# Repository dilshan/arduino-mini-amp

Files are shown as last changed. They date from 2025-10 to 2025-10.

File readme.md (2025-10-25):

# Arduino Mini Amplifier

The **Arduino Mini Amplifier** is a complete, open-source audio amplifier system that combines vintage analog audio processing with modern embedded control. It features Bluetooth and line-in audio inputs, tone adjustment, multiple stereo enhancement modes, and a 16-channel real-time audio spectrum analyzer displayed on an LCD.

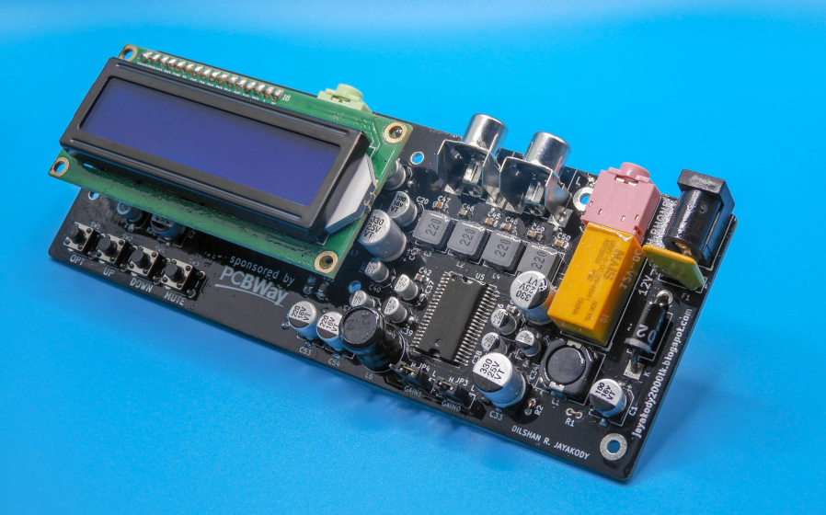
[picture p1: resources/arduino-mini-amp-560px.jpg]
Prototype build of the Arduino mini amplifier


At its core, this design integrates the Philips [TDA8425](https://www.alldatasheet.com/datasheet-pdf/download/19486/PHILIPS/TDA8425.html) analog audio processor - introduced in the late 1980s and known for its high-quality tone control system - with the Yamaha [YDA138](https://www.alldatasheet.com/datasheet-pdf/download/205149/YAMAHA/YDA138.html), a compact Class-D digital power amplifier that delivers up to 2×10 W RMS of clear, low-distortion stereo output.

An [ATmega328P](https://www.alldatasheet.com/datasheet-pdf/download/241077/ATMEL/ATMEGA328P.html) microcontroller platform ([Arduino Nano](https://docs.arduino.cc/resources/datasheets/A000005-datasheet.pdf)) manages all audio controls, user interface elements, and real-time visualizations.

## Features

- Based on Arduino Nano (ATmega328P)
- Bluetooth and Line-in audio input support
- 16-channel spectrum analyzer on 16×2 LCD
- Tone control (bass, treble) and mute function
- Speaker / Headphone output modes
- Stereo modes: Pseudo, Spatial, Linear, and Forced Mono
- Software control over all audio parameters via I2C

## Firmware

The firmware is written in C++ using the [Arduino framework](https://docs.platformio.org/en/latest/frameworks/arduino.html) and developed under [PlatformIO](https://platformio.org/).

To build and upload the firmware:

1. Install PlatformIO (as a [standalone tool or VS Code extension](https://platformio.org/platformio-ide)).
2. Clone this repository and open `arduino-amp-firmware` directory in PlatformIO.
3. Connect Arduino Nano (or compatible ATmega328P board) to the computer via USB.
4. From the PlatformIO toolbar or terminal, run:

```
pio run --target upload
```

This will compile and flash the firmware to the board automatically.

The firmware automatically initializes the audio processor, LCD, and input controls at startup. All adjustable parameters—such as tone, volume, and stereo mode - are stored in built-in EEPROM and restored on each power cycle.

## PCB and Hardware Design

This project is sponsored by [PCBWay](https://www.pcbway.com/). You can directly [order the PCB from PCBWay](https://www.pcbway.com/project/shareproject/Arduino_Mini_Amplifier_c5ac6d9c.html) or by uploading the Gerber files available in the [Releases](/dilshan/arduino-mini-amp/releases) section of this repository.

This amplifier has the following functional modules:

- **Audio Processor** – TDA8425-based tone and input control
- **Spectrum Analyzer** – 16-band with seperate NE5532 op-amp buffer
- **Power Amplifier** – Yamaha YDA138 Class-D stage (2 × 10 W RMS)
- **Bluetooth Source** – *AC6939* module with 78L05 regulator
- **Control Interface** – Arduino Nano, LCD, and tactile switches
- **Power Supply** – 12V DC input with multiple regulated rails

## License

This is a [certified open hardware project](https://certification.oshwa.org/lk000018.html) and all its design files, firmware source code, [documentation](https://github.com/dilshan/arduino-mini-amp/wiki), and other resource files are available at this project source repository. The content of this project is distributed under the terms of the following licenses:

- Hardware License: [CERN-OHL-W 2.0](https://ohwr.org/cern_ohl_w_v2.pdf)
- Software License: [MIT](/dilshan/arduino-mini-amp/blob/master/LICENSE)
- Documentation License: [CC BY 4.0](https://creativecommons.org/licenses/by/4.0/deed.en)

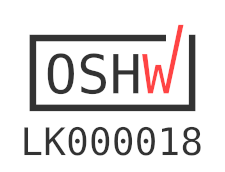
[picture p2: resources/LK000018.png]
LK000018 (https://certification.oshwa.org/lk000018.html)


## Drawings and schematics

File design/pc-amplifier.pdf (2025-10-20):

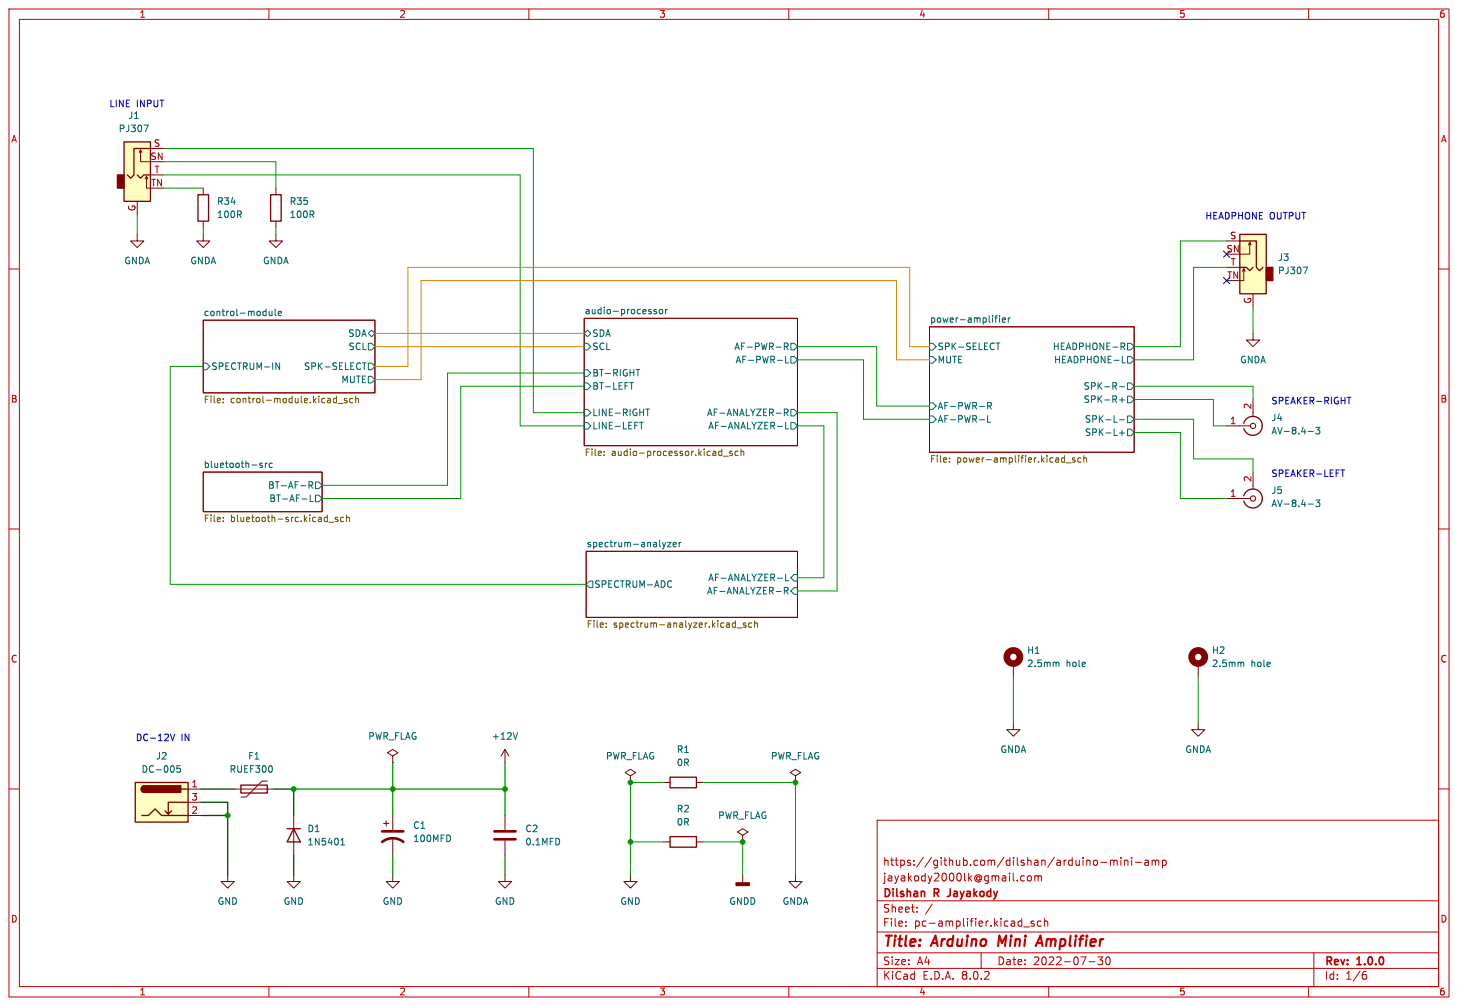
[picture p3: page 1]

audio-processor File: audio-processor.kicad_sch BT-AF-R

power-amplifier File: power-amplifier.kicad_sch SCL SDA

AF-ANALYZER-L AF-PWR-R

SPK-SELECT AF-PWR-R

AF-PWR-L BT-LEFT BT-RIGHT

https://github.com/dilshan/arduino-mini-amp

jayakody2000lk@gmail.com
R Jayakody | Id: 1/6 Title: Arduino Mini Amplifier File: pc-amplifier.kicad_sch Sheet: / Dilshan

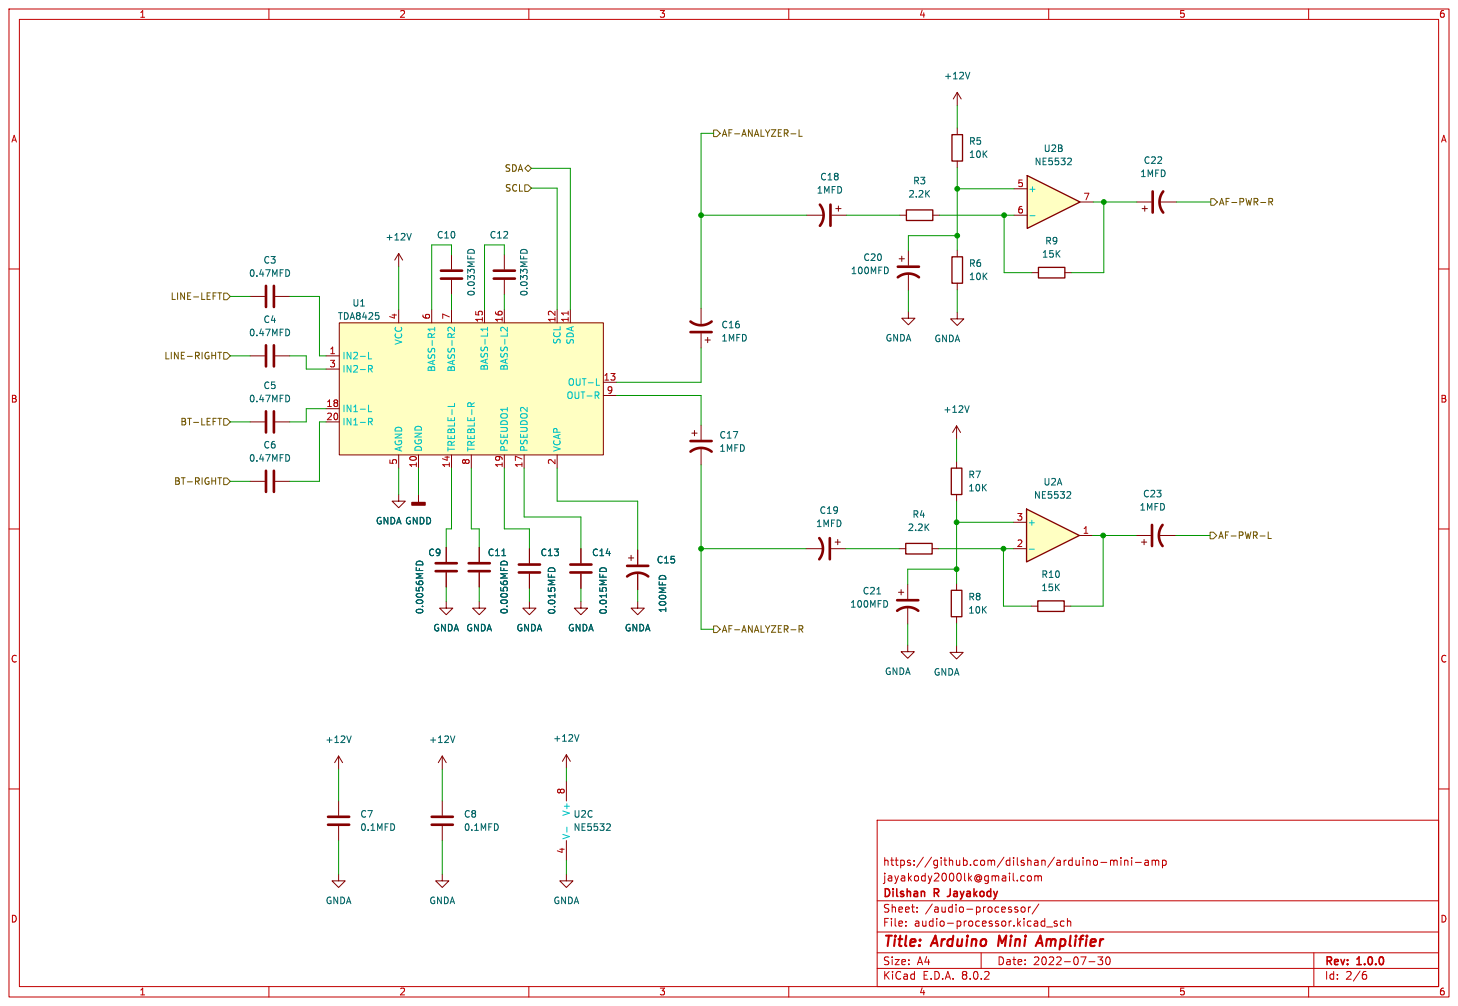
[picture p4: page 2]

https://github.com/dilshan/arduino-mini-amp

jayakody2000lk@gmail.com
R Jayakody | Id: 2/6 Title: Arduino Mini Amplifier File: audio-processor.kicad_sch Sheet: /audio-processor/ Dilshan

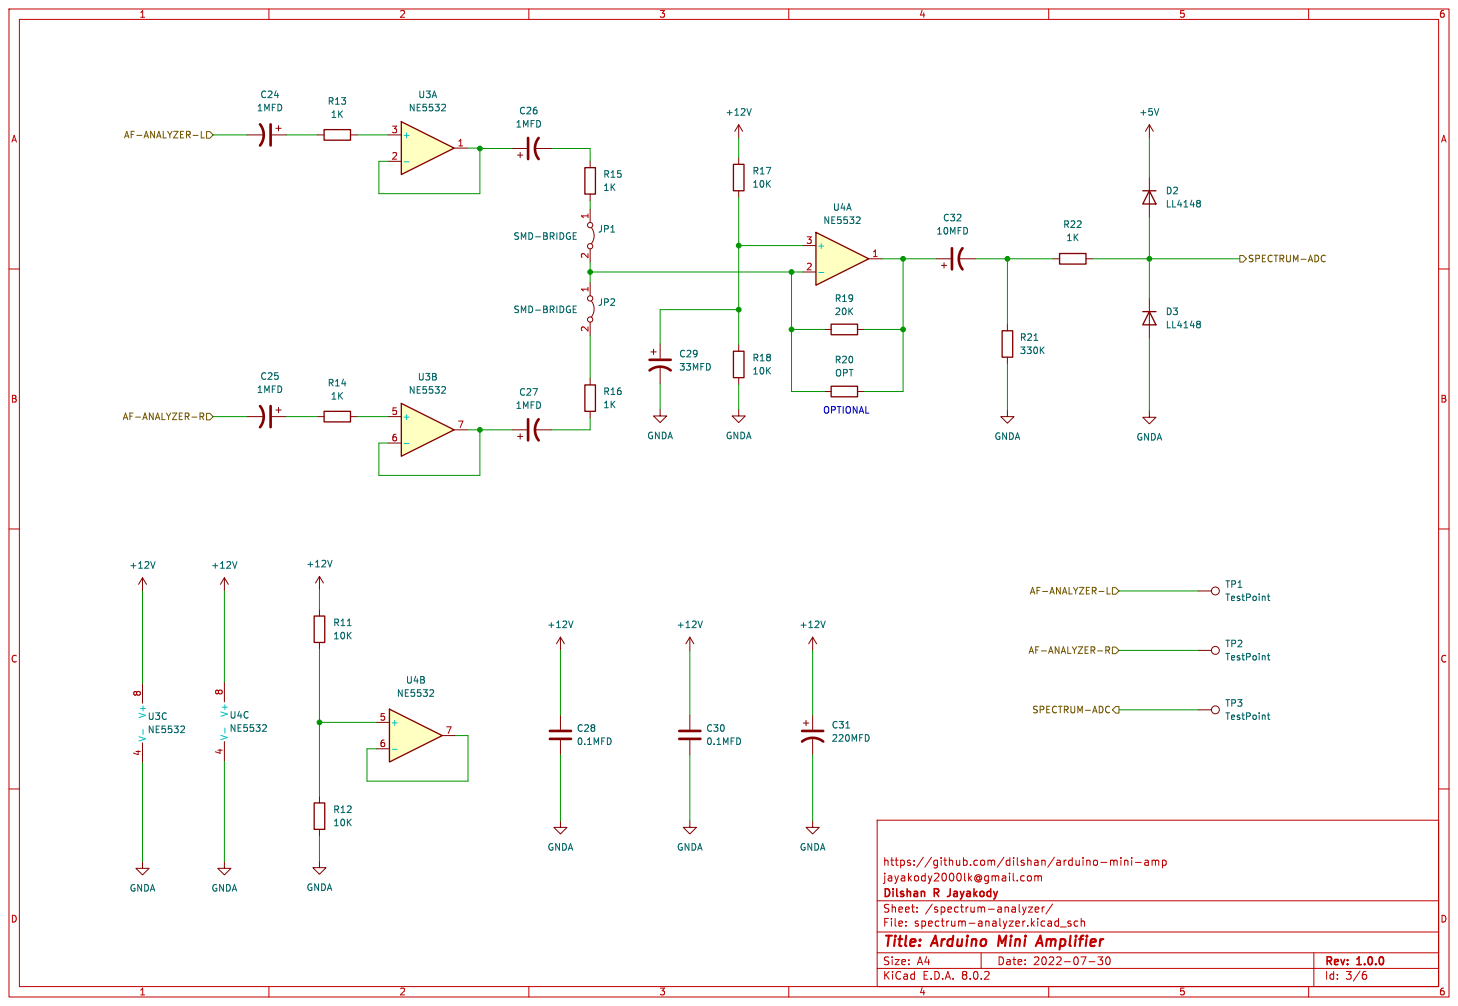
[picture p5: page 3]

AF-ANALYZER-L SPECTRUM-ADC

https://github.com/dilshan/arduino-mini-amp GNDA

jayakody2000lk@gmail.com
R Jayakody Id: 3/6 Title: Arduino Mini Amplifier File: spectrum-analyzer.kicad_sch Sheet: /spectrum-analyzer/ Dilshan

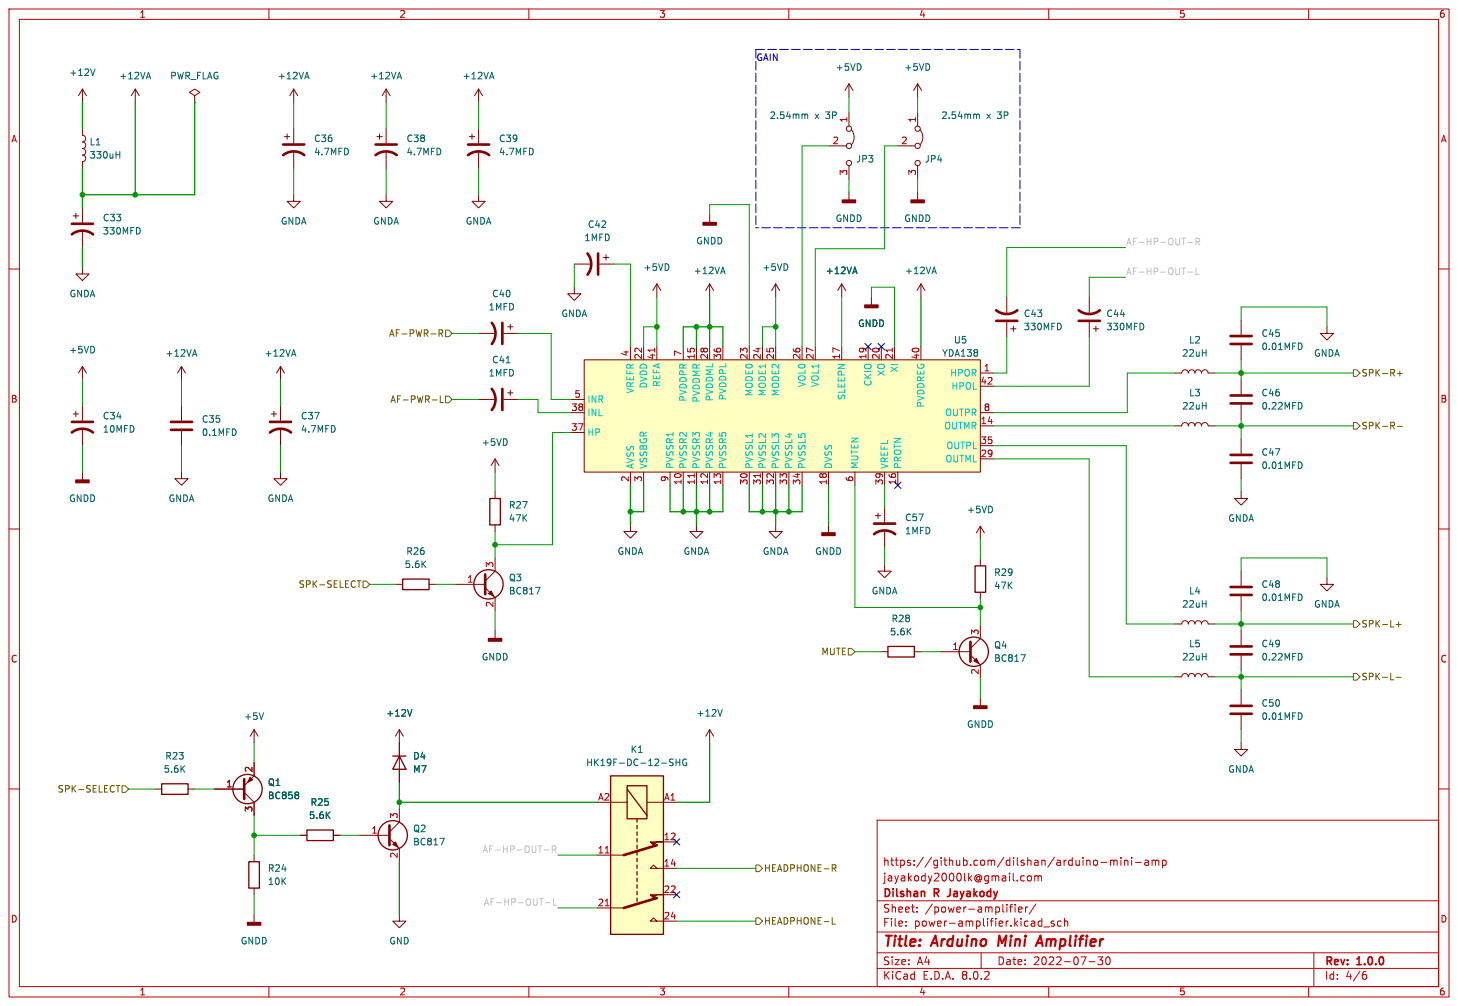
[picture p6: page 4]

AF-HP-OUT-L GAIN

2 XO 20 XI 21 DVDD 22 MODE0 23 MODE1 24 MODE2 25 VOL0 26 VOL1 27 PVDDML 28 OUTML 29 VSSBGR

SPK-L+ SPK-R+ SPK-R- HEADPHONE-L HEADPHONE-R

jayakody2000lk@gmail.com
R Jayakody | Id: 4/6 Title: Arduino Mini Amplifier File: power-amplifier.kicad_sch Sheet: /power-amplifier/ Dilshan

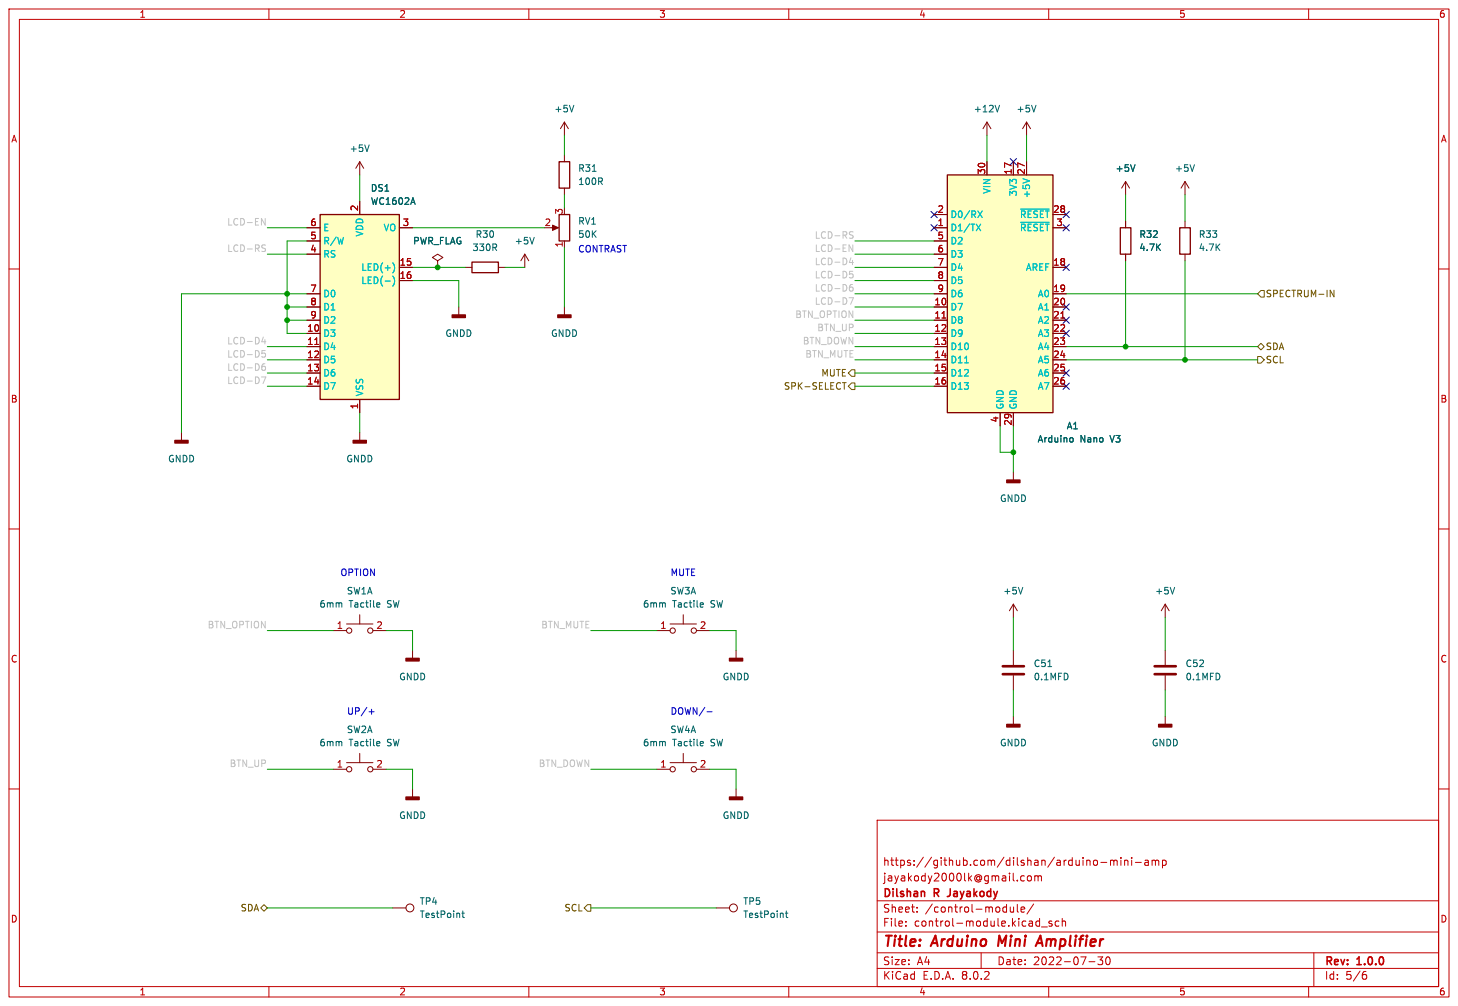
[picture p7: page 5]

https://github.com/dilshan/arduino-mini-amp
jayakody2000lk@gmail.com

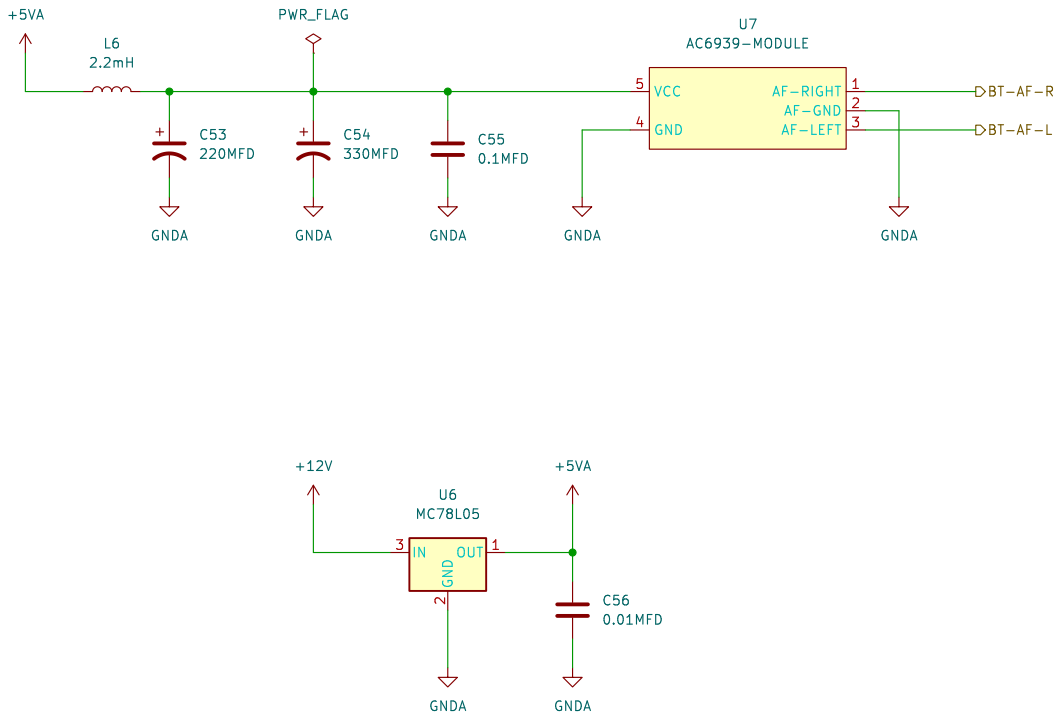
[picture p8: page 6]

https://github.com/dilshan/arduino-mini-amp
jayakody2000lk@gmail.com

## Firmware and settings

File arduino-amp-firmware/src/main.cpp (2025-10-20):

/*************************************************************************
  This file is part of the Arduino Mini Amplifier project.

  Copyright (c) 2025 Dilshan R Jayakody [jayakody2000lk at gmail d0t com]

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
  THE SOFTWARE IS PROVIDED "AS IS", WITHOUT WARRANTY OF ANY KIND,
  EXPRESS OR IMPLIED, INCLUDING BUT NOT LIMITED TO THE WARRANTIES OF
  MERCHANTABILITY, FITNESS FOR A PARTICULAR PURPOSE AND
  NONINFRINGEMENT. IN NO EVENT SHALL THE AUTHORS OR COPYRIGHT HOLDERS BE
  LIABLE FOR ANY CLAIM, DAMAGES OR OTHER LIABILITY, WHETHER IN AN ACTION
  OF CONTRACT, TORT OR OTHERWISE, ARISING FROM, OUT OF OR IN CONNECTION
  WITH THE SOFTWARE OR THE USE OR OTHER DEALINGS IN THE SOFTWARE.
*************************************************************************/

#include "common.h"
#include "tda8425.h"
#include "yda138.h"
#include "displayutil.h"

#include <Arduino.h>
#include <Wire.h>
#include <EEPROM.h>
#include <LiquidCrystal.h>
#include <fix_fft.h>

#define ANALYZER_SAMPLES        128
#define ANALYZER_COLUMNS        16
#define LCD_MAX_COLUMN_HEIGHT   16

unsigned char btnState_Action, btnState_Up, btnState_Down, btnState_Mute;
unsigned short idleCounter;
unsigned char audioOutMode, isAudioMute, isLCDShowMute;
AudioSettings audioSettings;

LiquidCrystal lcd(LCD_RS, LCD_EN, LCD_D4, LCD_D5, LCD_D6, LCD_D7);

char analogData[ANALYZER_SAMPLES];
char imgData[ANALYZER_SAMPLES];
int graphData[ANALYZER_SAMPLES];

// Spectrum analyzer (bar-graph) character configuration.
unsigned char graphLine1[] = {0x00, 0x00, 0x00, 0x00, 0x00, 0x00, 0x00, 0x1F};
unsigned char graphLine2[] = {0x00, 0x00, 0x00, 0x00, 0x00, 0x00, 0x1F, 0x1F};
unsigned char graphLine3[] = {0x00, 0x00, 0x00, 0x00, 0x00, 0x1F, 0x1F, 0x1F};
unsigned char graphLine4[] = {0x00, 0x00, 0x00, 0x00, 0x1F, 0x1F, 0x1F, 0x1F};
unsigned char graphLine5[] = {0x00, 0x00, 0x00, 0x1F, 0x1F, 0x1F, 0x1F, 0x1F};
unsigned char graphLine6[] = {0x00, 0x00, 0x1F, 0x1F, 0x1F, 0x1F, 0x1F, 0x1F};
unsigned char graphLine7[] = {0x00, 0x1F, 0x1F, 0x1F, 0x1F, 0x1F, 0x1F, 0x1F};

void saveConfiguration(AudioSettings *audioSettings, unsigned char *outputMode)
{
    // Save audio configurations.
    EEPROM.update(EEPROM_ADDR_VOLUME, audioSettings->volume);
    EEPROM.update(EEPROM_ADDR_BASS, audioSettings->bass);
    EEPROM.update(EEPROM_ADDR_TREBLE, audioSettings->treble);
    EEPROM.update(EEPROM_ADDR_SWCONF, audioSettings->switchConfig);

    // Save audio output mode.
    EEPROM.update(EEPROM_ADDR_OUTPUT, *outputMode);
}

unsigned char loadLastConfiguration(AudioSettings *audioSettings, unsigned char *outputMode)
{
    AudioSettings tempSettings;
    unsigned char tempOutputMode;
    unsigned char isValueUpdate = FALSE;
    
    // Load audio configuration.
    tempSettings.volume = EEPROM.read(EEPROM_ADDR_VOLUME);
    tempSettings.bass = EEPROM.read(EEPROM_ADDR_BASS);
    tempSettings.treble = EEPROM.read(EEPROM_ADDR_TREBLE);
    tempSettings.switchConfig = EEPROM.read(EEPROM_ADDR_SWCONF);

    // Load audio output mode.
    tempOutputMode = EEPROM.read(EEPROM_ADDR_OUTPUT);

    // Assign only the valid audio configurations.
    if(tempSettings.volume <= VOLUME_TDA8425_MAX)
    {
        audioSettings->volume = tempSettings.volume;
        audioSettings->switchConfig = tempSettings.switchConfig;
        isValueUpdate = TRUE;
    }

    if(tempSettings.bass <= BASS_TDA8425_MAX)
    {
        audioSettings->bass = tempSettings.bass;
        isValueUpdate = TRUE;
    }

    if(tempSettings.treble <= TREBLE_TDA8425_MAX)
    {
        audioSettings->treble = tempSettings.treble;
        isValueUpdate = TRUE;
    }

    // Assign only the valid audio output configurations.
    if(tempOutputMode <= AUDIO_OUT_HEADPHONE)
    {
        *outputMode = tempOutputMode;
        isValueUpdate = TRUE;
    }

    return isValueUpdate;
}

void drawSpectrumAnalyzer()
{
    unsigned char arrayPos = 1;
    unsigned char lcdPos = 0;
    int barVal;

    while(lcdPos < ANALYZER_COLUMNS)
    {        
        // Check graph data is moving more than one LCD row.
        if(graphData[arrayPos] > 8)
        {            
            barVal = graphData[arrayPos] - 8;  
            
            lcd.setCursor(lcdPos, 0);        

            // Fill the top row of the LCD.
            if(barVal > 0)
            {     
                lcd.write((char)((barVal < 8) ? barVal : 0xFF)); 
            }
            
            // In this state bottom row of the LCD is always full.
            barVal = 0xFF;                    
        }
        else
        {
            barVal = graphData[arrayPos];

            // Check for valid graph data.
            if(barVal > 0)
            {
                barVal = (barVal < 8) ? barVal : 0xFF;
            }
            else
            {
                // Graph data is not available for the selected frequency.
                barVal = 0;
            }
        }

        // Draw the bottom raw of the LCD.
        lcd.setCursor(lcdPos, 1);

        if(barVal > 0)
        {
            lcd.write((char)barVal); 
        }

        // Move to next LCD column and frequency.
        arrayPos += 2;
        lcdPos++;
    }
}

void automaticGainControl(int *graph)
{
    unsigned char peekDataCount = 0;
    unsigned char arrayPos;
    int temp = 0;

    // Find the number of peek points across the spectrum and the maximum amplitude.
    for(arrayPos = 1; arrayPos < ((ANALYZER_COLUMNS * 2) + 1); arrayPos++)
    {
        if(graph[arrayPos] > LCD_MAX_COLUMN_HEIGHT)
        {
            peekDataCount++;
        }

        if(graph[arrayPos] > temp)
        {
            temp = graph[arrayPos];
        }
    }

    // Trim graph data based on the maximum amplitude.
    if(peekDataCount >= (ANALYZER_COLUMNS / 2))
    {
        temp = temp % LCD_MAX_COLUMN_HEIGHT;
        if(temp > 0)
        {
            for(arrayPos = 1; arrayPos < ((ANALYZER_COLUMNS * 2) + 1); arrayPos++)
            {
                graph[arrayPos] = graph[arrayPos] / temp;
            }
        }
    }
}

void updateSpectrumAnalyzer()
{
    unsigned char samplePos, tempPos;
    char tempValue;

    // Capture audio data from ADC channel 0.
    for(samplePos = 0; samplePos < ANALYZER_SAMPLES; samplePos++)
    { 
        tempValue = analogRead(A0);
        analogData[samplePos] = (char)(tempValue/4 - 128);
        imgData[samplePos] = 0;
    }

    // Perform FFT.
    fix_fft(analogData, imgData, 7, 0);

    // Extract absolute value from FFT data.
    for(samplePos = 0; samplePos < (ANALYZER_SAMPLES/2); samplePos++)
    {
        graphData[samplePos] = (int)sqrt(analogData[samplePos] * analogData[samplePos] + imgData[samplePos] * imgData[samplePos]);
    }

    for(samplePos = 0, tempPos = 0; samplePos < (ANALYZER_SAMPLES/2); samplePos++, tempPos += 2)
    {
        graphData[samplePos] = graphData[tempPos] + graphData[tempPos + 1];
    }

    // Trim graph data to avoid clipping.
    automaticGainControl(graphData);

    // Draw graph data on LCD.
    lcd.clear();    
    drawSpectrumAnalyzer();
}

void settingsMenuLoop()
{
    unsigned char temp;
    SettingsMenuState menuState = INPUT_CHANNEL;
    idleCounter = 0;
    
    // Update button states on global variables.
    btnState_Action = digitalRead(SWITCH_ACTION);
    btnState_Up = digitalRead(SWITCH_UP);
    btnState_Down = digitalRead(SWITCH_DOWN);
    btnState_Mute = digitalRead(SWITCH_MUTE);

    lcd.clear();
    lcd.print("Settings");
    displayMenuItem(&menuState, &audioSettings, &audioOutMode);
    
    while(1)
    {
        if((btnState_Action == LOW) && (digitalRead(SWITCH_ACTION) == HIGH))
        {
            // Action button press event.  
            menuState = (menuState != EXIT) ? ((SettingsMenuState)(menuState + 1)) : INPUT_CHANNEL;
            displayMenuItem(&menuState, &audioSettings, &audioOutMode);

            idleCounter = 0;
        }

        if((btnState_Mute == LOW) && (digitalRead(SWITCH_MUTE) == HIGH))
        {
            // Mute audio in sound processor and the power amplifier.
            isAudioMute = (audioSettings.switchConfig & SWITCH_MUTE_TDA8425) ? FALSE : TRUE;

            setPowerAmpMute(isAudioMute);
            muteAudio(&audioSettings, isAudioMute);        

            idleCounter = 0; 
            isLCDShowMute = TRUE;

            delay(50);
        }

        if((btnState_Up == LOW) && (digitalRead(SWITCH_UP) == HIGH))
        {
            // Up button press event.
            switch(menuState)
            {
                case INPUT_CHANNEL:
                    // Rotate to next source selection mode ranging from 0x02 to 0x07.
                    temp = audioSettings.switchConfig & 0x07;                                        
                    temp = (temp >= 0x07) ? 0x02 : (temp + 1);
                    audioSettings.switchConfig = (audioSettings.switchConfig & 0xF8) | temp;
                    setSwitchConfiguration(&audioSettings);
                    break;
                case LVL_BASS:
                    // Increase bass level and stop at the max level.
                    audioSettings.bass = (audioSettings.bass < BASS_TDA8425_MAX) ? (audioSettings.bass + 1) : BASS_TDA8425_MAX;
                    setBass(&audioSettings);
                    break;
                case LVL_TREBLE:
                    // Increase treble level and stop and the max level.
                    audioSettings.treble = (audioSettings.treble < TREBLE_TDA8425_MAX) ? (audioSettings.treble + 1) : TREBLE_TDA8425_MAX;
                    setTreble(&audioSettings);
                    break;
                case MODE_STEREO:
                    // Rotate to next channel mode ranging from 0x00 to 0x03.
                    temp = (audioSettings.switchConfig & 0x18) >> 3;
                    temp = (temp >= 0x03) ? 0x00 : (temp + 1);
                    audioSettings.switchConfig = (audioSettings.switchConfig & 0xE7) | (temp << 3);
                    setSwitchConfiguration(&audioSettings);
                    break;
                case OUTPUT_MODE:
                    // Audio output mode (speaker or headphone selection).
                    audioOutMode = (audioOutMode == AUDIO_OUT_SPEAKER) ? AUDIO_OUT_HEADPHONE : AUDIO_OUT_SPEAKER;
                    setAudioOutputMode(audioOutMode);
                    break;
                case EXIT:
                    // Save the changes and exit from the settings menu.
                    saveConfiguration(&audioSettings, &audioOutMode);
                    return;                    
            }

            // Update display with new configuration / level.
            displayMenuItem(&menuState, &audioSettings, &audioOutMode);

            idleCounter = 0;
        }

        if((btnState_Down == LOW) && (digitalRead(SWITCH_DOWN) == HIGH))
        {
            // Down button press event.
            switch(menuState)
            {
                case INPUT_CHANNEL:
                    // Rotate to next source selection mode ranging from 0x02 to 0x07.
                    temp = audioSettings.switchConfig & 0x07;                                        
                    temp = (temp == 0x02) ? 0x07 : (temp - 1);
                    audioSettings.switchConfig = (audioSettings.switchConfig & 0xF8) | temp;
                    setSwitchConfiguration(&audioSettings);
                    break;
                case LVL_BASS:
                    // Increase bass level and stop at the min level.
                    audioSettings.bass = (audioSettings.bass > BASS_TDA8425_MIN) ? (audioSettings.bass - 1) : BASS_TDA8425_MIN;
                    setBass(&audioSettings);
                    break;
                case LVL_TREBLE:
                    // Increase treble level and stop and the min level.
                    audioSettings.treble = (audioSettings.treble > TREBLE_TDA8425_MIN) ? (audioSettings.treble - 1) : TREBLE_TDA8425_MIN;
                    setTreble(&audioSettings);
                    break;
                case MODE_STEREO:
                    // Rotate to next channel mode ranging from 0x00 to 0x03.
                    temp = (audioSettings.switchConfig & 0x18) >> 3;
                    temp = (temp == 0x00) ? 0x03 : (temp - 1);
                    audioSettings.switchConfig = (audioSettings.switchConfig & 0xE7) | (temp << 3);
                    setSwitchConfiguration(&audioSettings);
                    break;
                case OUTPUT_MODE:
                    // Audio output mode (speaker or headphone selection).
                    audioOutMode = (audioOutMode == AUDIO_OUT_SPEAKER) ? AUDIO_OUT_HEADPHONE : AUDIO_OUT_SPEAKER;
                    setAudioOutputMode(audioOutMode);
                    break;
                case EXIT:
                    // Save the changes and exit from the settings menu.
                    saveConfiguration(&audioSettings, &audioOutMode);
                    return;                    
            }

            // Update display with new configuration / level.
            displayMenuItem(&menuState, &audioSettings, &audioOutMode);

            idleCounter = 0;
        }  
        
        // Update button states.
        btnState_Action = digitalRead(SWITCH_ACTION);
        btnState_Up = digitalRead(SWITCH_UP);
        btnState_Down = digitalRead(SWITCH_DOWN);  
        btnState_Mute = digitalRead(SWITCH_MUTE);     

        // Check for idle timeout.
        if(idleCounter >= IDLE_MENU_TIMEOUT)
        {
            // Idle timeout!, lets exit from the settings menu.
            saveConfiguration(&audioSettings, &audioOutMode);
            return;
        }
        else
        {
            // User is recently interacted with the system!
            idleCounter++;
            delay(50);             
        }
    }
}

void setup() 
{    
    // Initialize Arduino libraries required for I2C and LCD.
    lcd.begin(16, 2);
    lcd.clear();

    Wire.begin(); 
    
    // Configure I/O pins.
    pinMode(SWITCH_ACTION, INPUT_PULLUP);
    pinMode(SWITCH_UP, INPUT_PULLUP);
    pinMode(SWITCH_DOWN, INPUT_PULLUP);
    pinMode(SWITCH_MUTE, INPUT_PULLUP);
       
    // Initialize TDA8425 audio processor (on I2C bus).
    initSoundProcessor(&audioSettings);

    // Setup global variables.
    btnState_Action = digitalRead(SWITCH_ACTION);
    btnState_Up = digitalRead(SWITCH_UP);
    btnState_Down = digitalRead(SWITCH_DOWN);
    btnState_Mute = digitalRead(SWITCH_MUTE);

    audioOutMode  = AUDIO_OUT_SPEAKER;
    idleCounter = IDLE_TIMEOUT;
    isAudioMute = FALSE;
    isLCDShowMute = FALSE;

    // Restore last audio configuration.
    if(loadLastConfiguration(&audioSettings, &audioOutMode))
    {
        // Apply TDA8425 audio processor related configurations.
        setVolume(&audioSettings);
        setBass(&audioSettings);
        setTreble(&audioSettings);
        setSwitchConfiguration(&audioSettings);
    }

    // Release mute in TDA8425 audio processor and power amplifier.
    muteAudio(&audioSettings, isAudioMute);
    setPowerAmpMute(isAudioMute);

    // Activate last audio output.
    setAudioOutputMode(audioOutMode);

    // Define custom characters required for the spectrum analyzer.
    lcd.createChar(1, graphLine1);
    lcd.createChar(2, graphLine2);
    lcd.createChar(3, graphLine3);
    lcd.createChar(4, graphLine4);
    lcd.createChar(5, graphLine5);
    lcd.createChar(6, graphLine6);
    lcd.createChar(7, graphLine7);
}

void loop() 
{
    if((btnState_Action == LOW) && (digitalRead(SWITCH_ACTION) == HIGH))
    {
        // Action button press event.  
        settingsMenuLoop();  

        // Wait until the exit button is released by the user.
        while(!((digitalRead(SWITCH_UP) == HIGH) && (digitalRead(SWITCH_DOWN) == HIGH)))
        {
            delay(5);
        }

        // Update button state variables.
        btnState_Action = digitalRead(SWITCH_ACTION);
        btnState_Up = digitalRead(SWITCH_UP);
        btnState_Down = digitalRead(SWITCH_DOWN);
        btnState_Mute = digitalRead(SWITCH_MUTE);

        idleCounter = IDLE_TIMEOUT;                    
    }

    if((btnState_Mute == LOW) && (digitalRead(SWITCH_MUTE) == HIGH))
    {
        // Mute audio in sound processor and the power amplifier.
        isAudioMute = (audioSettings.switchConfig & SWITCH_MUTE_TDA8425) ? FALSE : TRUE;

        setPowerAmpMute(isAudioMute);
        muteAudio(&audioSettings, isAudioMute);     

        idleCounter = IDLE_TIMEOUT; 
        isLCDShowMute = TRUE;

        delay(50);
    }

    if(isAudioMute == FALSE)
    {        
        // Change volume only if the mute is released.

        if((btnState_Up == LOW) && (digitalRead(SWITCH_UP) == HIGH))
        {
            // Up button press event.        
            audioSettings.volume = (audioSettings.volume < VOLUME_TDA8425_MAX) ? (audioSettings.volume + 1) : audioSettings.volume;
            setVolume(&audioSettings);
            displayVolumeLevel(audioSettings.volume);
            idleCounter = 0;        
        }

        if((btnState_Down == LOW) && (digitalRead(SWITCH_DOWN) == HIGH))
        {
            // Down button press event.
            audioSettings.volume = (audioSettings.volume > VOLUME_TDA8425_MIN) ? (audioSettings.volume - 1) : audioSettings.volume;
            setVolume(&audioSettings);
            displayVolumeLevel(audioSettings.volume);
            idleCounter = 0;
        } 
    }
    else
    {
        // Check status of the volume up or down buttons.
        if(((btnState_Up == LOW) && (digitalRead(SWITCH_UP) == HIGH)) || ((btnState_Down == LOW) && (digitalRead(SWITCH_DOWN) == HIGH)))
        {
            // Release mute if the volume button(s) are pressed.
            isAudioMute = FALSE;

            setPowerAmpMute(isAudioMute);
            muteAudio(&audioSettings, isAudioMute);     

            // Show current volume level.
            displayVolumeLevel(audioSettings.volume);
            idleCounter = 0; 

            isLCDShowMute = FALSE;
        }
        
        // System is in mute state, and show MUTE on LCD.
        if(isLCDShowMute == TRUE)
        {
            isLCDShowMute = FALSE;
            showMute();            
        }
    }   

    // Update button states.
    btnState_Action = digitalRead(SWITCH_ACTION);
    btnState_Up = digitalRead(SWITCH_UP);
    btnState_Down = digitalRead(SWITCH_DOWN);
    btnState_Mute = digitalRead(SWITCH_MUTE);

    // To minimize the write cycles, let save the current volume level at the middle 
    // of timeout interval.
    if(idleCounter == (IDLE_TIMEOUT / 2))
    {
        saveConfiguration(&audioSettings, &audioOutMode);
    }
    
    // Place this code block at the bottom of the service loop.
    if(isAudioMute == FALSE)
    {
        // Idle detection is checked only if the output is not mute.
        if(idleCounter >= IDLE_TIMEOUT)
        {
            // System is in idle state (and display the spectrum analyzer).
            updateSpectrumAnalyzer();
            delay(5);
        }
        else
        {
            // User is recently interacted with the system!
            idleCounter++;
            delay(50);
        }
    }
    else
    {
        // System is in MUTE. 50ms delay is placed for button debouncing.
        delay(50);
    }    
}

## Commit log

2022-07-26 Initial version of amplifier schematic.
    [audio-processor.kicad_sch, bluetooth-src.kicad_sch, control-module.kicad_sch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]
2022-07-28 Initial version of the PCB.
    [pc-amplifier.kicad_pcb, pc-amplifier.kicad_sch, power-amplifier.kicad_sch]
2022-07-30 Routed PCB design for REV 1.0.
    [pc-amplifier.kicad_pcb, pc-amplifier.kicad_sch, power-amplifier.kicad_sch]
2022-07-30 Add page settings to PCB and schematic.
    [audio-processor.kicad_sch, bluetooth-src.kicad_sch, control-module.kicad_sch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]
2022-07-30 Fix silkscreen offset issues in front layer.
    [pc-amplifier.kicad_pcb]
2022-07-30 Fix part reference issues in PCB.
    [pc-amplifier.kicad_pcb]
2022-07-30 Fix track width issues in PCB.
    [pc-amplifier.kicad_pcb]
2022-07-30 Fix fill issue in GNDD top layer.
    [pc-amplifier.kicad_pcb]
2025-10-20 Convert project to support new KiCAD versions.
    [audio-processor.kicad_sch, bluetooth-src.kicad_sch, control-module.kicad_sch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]
2025-10-20 Add image of the prototype build.
2025-10-21 Add image of the prototype build into readme.
2025-10-21 Update PCBWay link in README
2025-10-22 Update PCB ordering link in README
